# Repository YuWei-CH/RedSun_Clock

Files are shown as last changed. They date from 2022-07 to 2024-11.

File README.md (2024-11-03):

# RedSun_Clock
RedSun_Clock is a PCB-based clock that I designed and developed independently. The project was guided by Mr.Ethan and Mr.Matthew during the Google Hardware Product Sprint (HPS2022 Summer). 

This project consists of two main parts: Hardware and Software.

## Hardware
The hardware part includes the design of the circuit board and the bill of materials (BOM).
Essential components:
LED Matrix  
Micro-controller(atmega328)  
Quartz crystal unit  
Printed Circuit Board  

## Software
The software part is composed of code written in Arduino, which drives the operation of the hardware. And I use KiCAD for PCB design and verification.

## How to compile the code
You can use the Arduino compiler to compile this code.

## Picture
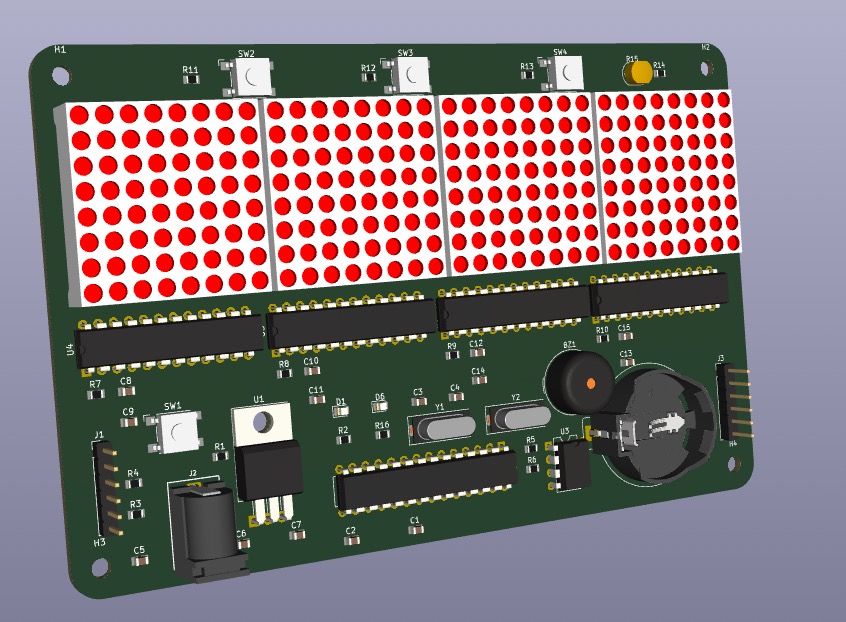
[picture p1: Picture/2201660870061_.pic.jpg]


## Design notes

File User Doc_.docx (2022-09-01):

User Doc

RedSun Clock is a smart clock based on ATmega328p. The RedSun Clock uses a beautiful dot matrix as the display module and makes it easy to read the time and information.

1. Design and architecture

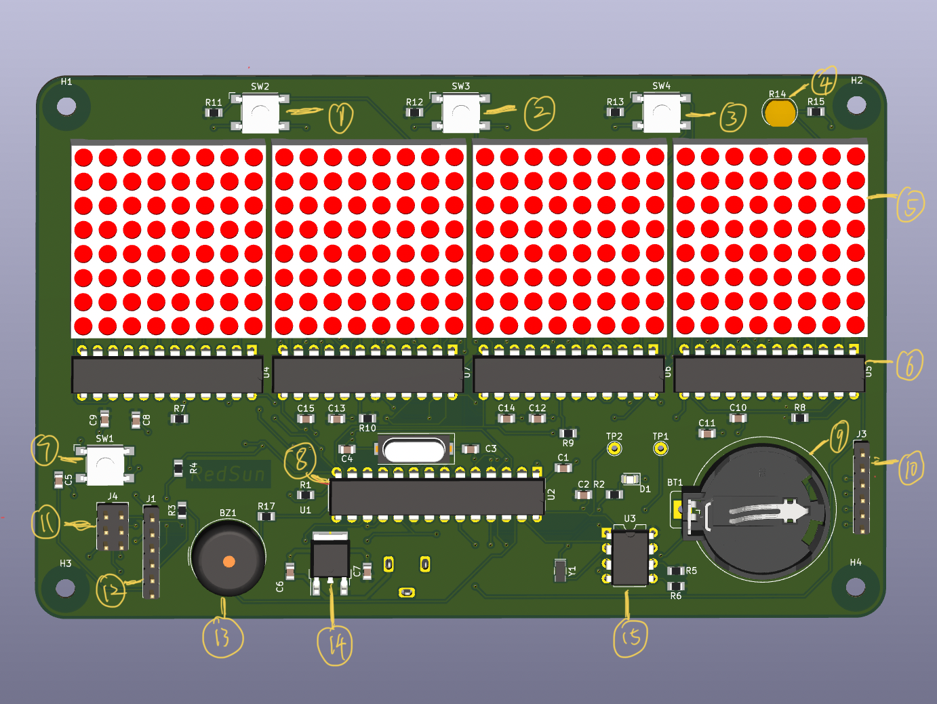
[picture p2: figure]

（Front 3D View of RedSum Clock）

- 1.Up/Daytime button
- 2.Down/ Datetime button
- 3.Sel/ Seconds button
- 4.Photoresistor
- 5. 8*8*4 dot matrix display
- 6. Max7219 chip(display processing chip)
- 7. Reset button
- 8. ATmega328P chip(micro controller)
- 9. Battery for RTC(real time clock)
- 10. Serial pins for joysticker
- 11. I/O pins
- 12. Serial pins
- 13. Alarm buzzer
- 14. Power management chip
- 15. DS1307 module (RTC)

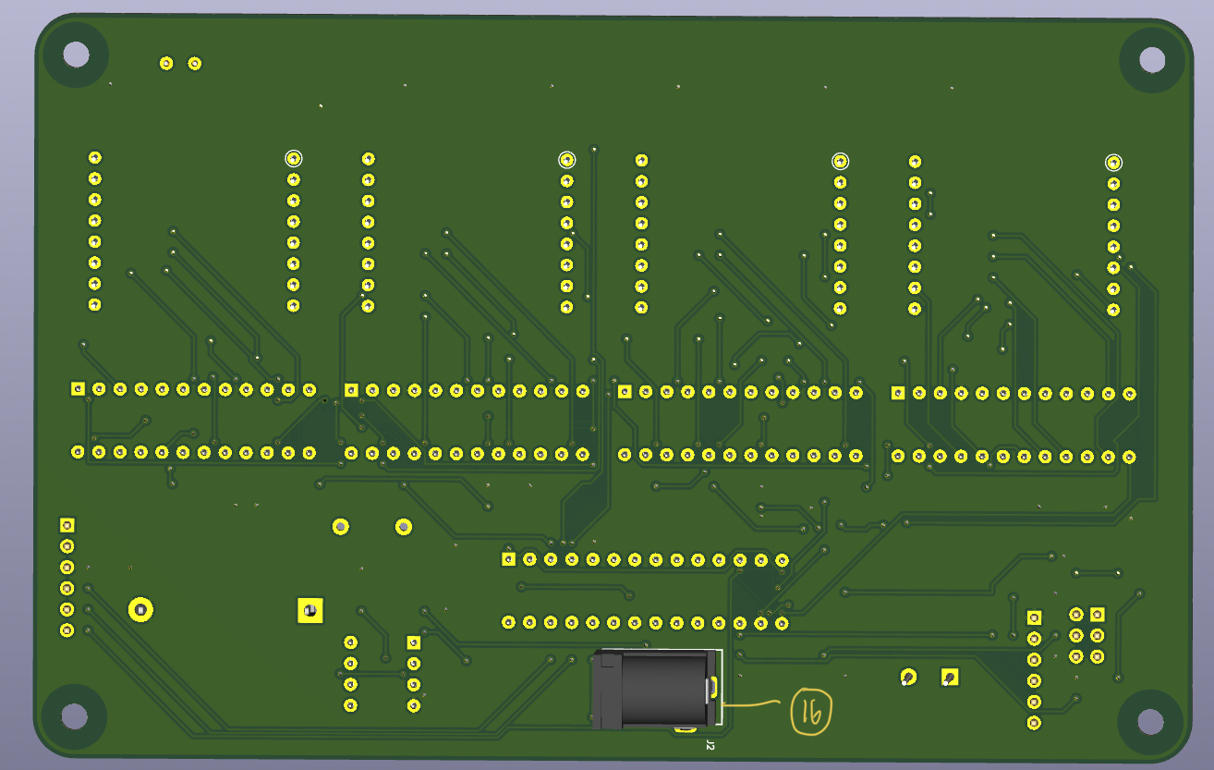
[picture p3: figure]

(Back 3D View of RedSum Clock)

- 16. Power supply
2. End-User Guide (Functions, charges, requirements)

Functions:

Time display function: When the RedSun Clock is powered on, the time will be automatically displayed on the display module. If you need to display Datetime, please press (2-button). If seconds need to be displayed, press (3-button).

Alarm Clock Function: The alarm clock function can be used when the RedSun Clock is powered on. To use the alarm function, press the Joysticker first, then the RedSun Clock will display "00:00" (if other content is displayed, please refer to the common question section). Once the screen correctly displays "00:00", the user can use the joysticker to set the time of the alarm. joysticker up increases the time and down decreases the time. To the left or to the right is to switch between hours and minutes. When the alarm is set, press the joysticker again and the alarm will be saved.

Charges：

A 9v battery can be used to provide power or a round interface charger with a power adaptor. Do not touch the circuit in the energized state to avoid electric shock or short circuit.

Requirements：

1. Please keep your RedSun Clock in a dry and ventilated environment. Please also avoid direct sunlight.

2. It is necessary to install a RedSun Clock into the plastic case.

3. If the RedSun Clock overheats, please disconnect the power promptly.

Please do not touch the circuit board with conductors or live objects.

3. Source code address and simple code address

Code resource: https://github.com/YuWei-CH/Yuwei_Clock/tree/main/Code/ClockCode

Test code link: https://github.com/YuWei-CH/Yuwei_Clock/tree/main/Code/Test

(If there is a functional problem on RedSun Clock, you can use the Test code to troubleshoot it.)

4. Test guide

If users have solid knowledge of EE and CS, they can use Test plan to self-test.

0. Visual Inspection:

1.Mechanical Damage

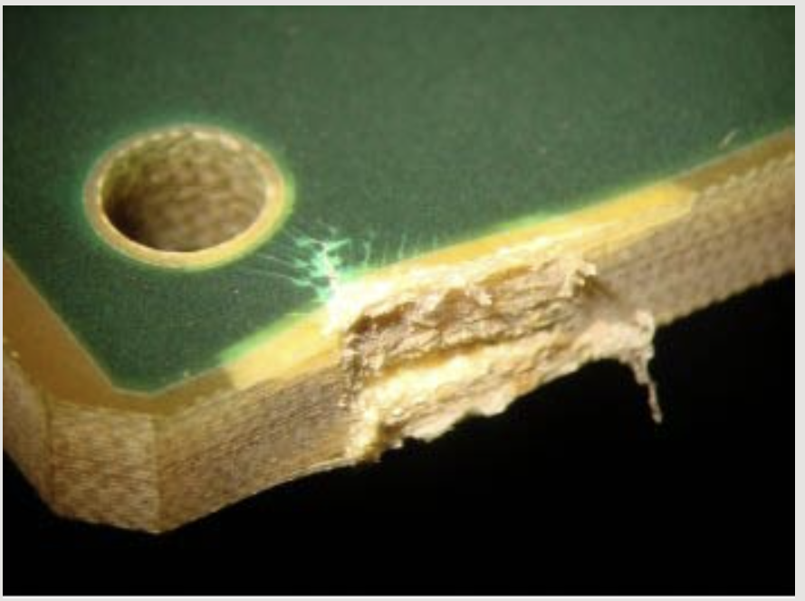
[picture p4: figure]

2.Copper Scratches

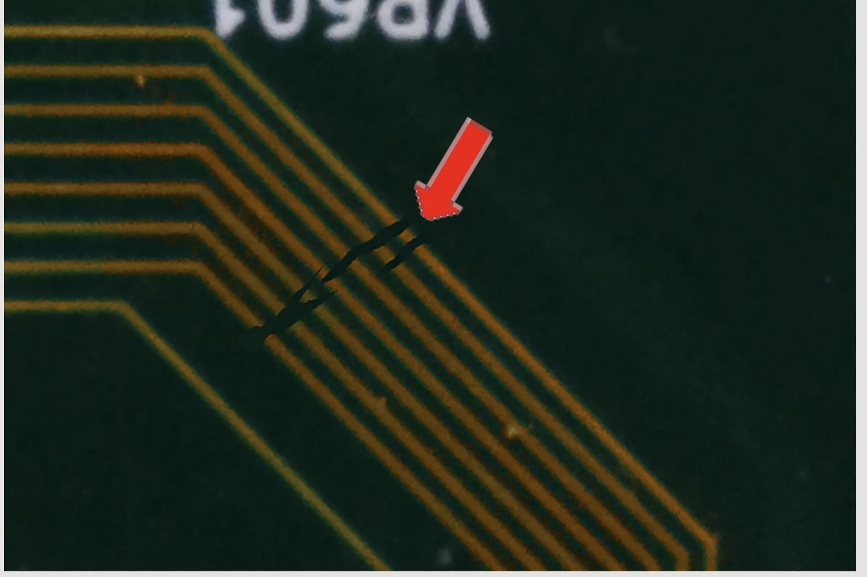
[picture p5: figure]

3.Solder Bridging

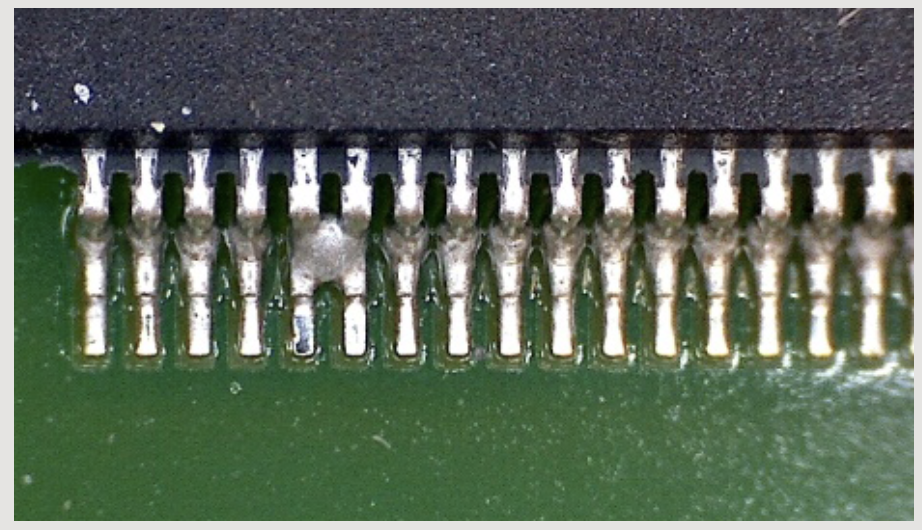
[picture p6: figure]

4.Cold Solder Joint

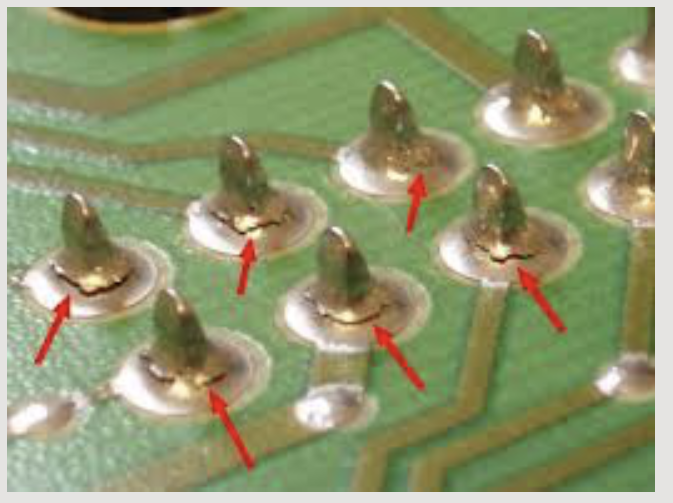
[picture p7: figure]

1. LED:

1.Test power and luminance of LED.

2.Run LED_blink code to test LED and Button

2. Button:

1.4 pins of the button are intact and working properly.

3. DS1307:

1.Can be powered by the breadboard

2.Battery works properly

3.You can use the 3 tests of Memory.ino

4.Capable of accurate time feedback (9600)

5. Touch the test pin with a voltmeter, the voltmeter should show the value

4.Dot matrix:

1. Test by “double for-loop print” which lights up each dot one by one, test whether each dot can be properly displayed.

2. Light up each row and test if there are any short circuits.

3. Call the display function to display the number.

4. Test the code in Dot_matrix_display

5. Buzzer:

1.Make sure it can sound through run code buzzer code

6. Joysticker:

1.Toggle the joysticker in all four directions and observe the values displayed by Serial.

2.Press the joysticker to make sure the value of SW in Serial has changed.

7. Power:

1.Use a voltmeter to connect the test pin next to the power supply, the voltmeter voltage reading should be 5v-9v

8. Basic Function:

Run the code in Yuwei_Clock/Code/Test one by one. Each component should have a corresponding reaction, for example, the LED will blink and Dot_matric will show the pattern.

9.Advance Function:

1. Does the Dot matrix display the correct time (hour:minute)?

2. Does the dot matrix display the date time (month/day/year) when the middle button is pressed?

3. Does the dot matrix show seconds after pressing the right button?

4. Does the dot matrix turn dark after covering the photoresistor with your hand?

5. Does the LED light up when the joysticker is pressed?

6. After pressing the joysticker, the system will enter the alarm setting mode. Is the dot matrix displayed correctly when moving the joysticker up and down and left and right?

7. After the alarm is set, does the buzzer go off at the alarm time and turn off within 4 seconds?

5. Help guide && Common questions and problems

What to do if the alarm clock does not display: First, please restart RedSun Clock to ensure that the power supply is working properly. If there is no response after reboot, please press 1-button. if you have completed the above operations, you can try upload test code to troubleshoot the problem.

The clock displays the wrong content: If the content displayed is digital you can update the program again to reset the RTC.

Inaccurate time: Please check if the RTC battery is properly powered. If the displayed number is three digits, please refer to question 2.

The button is not responding: Please restart RedSun Clock to reset the hardware system. If there is no response after reboot, please check if the pins of the button are broken and if there are scratches on the circuit board under the button. If the problem persists, it is a hardware issue.

Joysticker is not responding: Please check if the Pins are properly connected. secondly, you can check if there is a short circuit in the connection of joysticker.

The alarm clock is not responding: First, please try to reset the alarm clock. If it still does not respond you can follow the order of (buzzer, joysticker and RTC) to check if the hardware is intact. If the hardware is intact, please upload the test code about the alarm to troubleshoot the problem.

The alarm clock can not be turned off automatically: first of all, it is recommended to turn off the RedSun clock, and then you can check whether the buzzer is short-circuited. If there is no problem, please re-upload the program.

What to do if you get an error writing the program: Please update the environment of Arduino IDE. Go to Arduino and click update one by one in the managed libraries window. If you have any problems with the program, please leave a comment on Github.

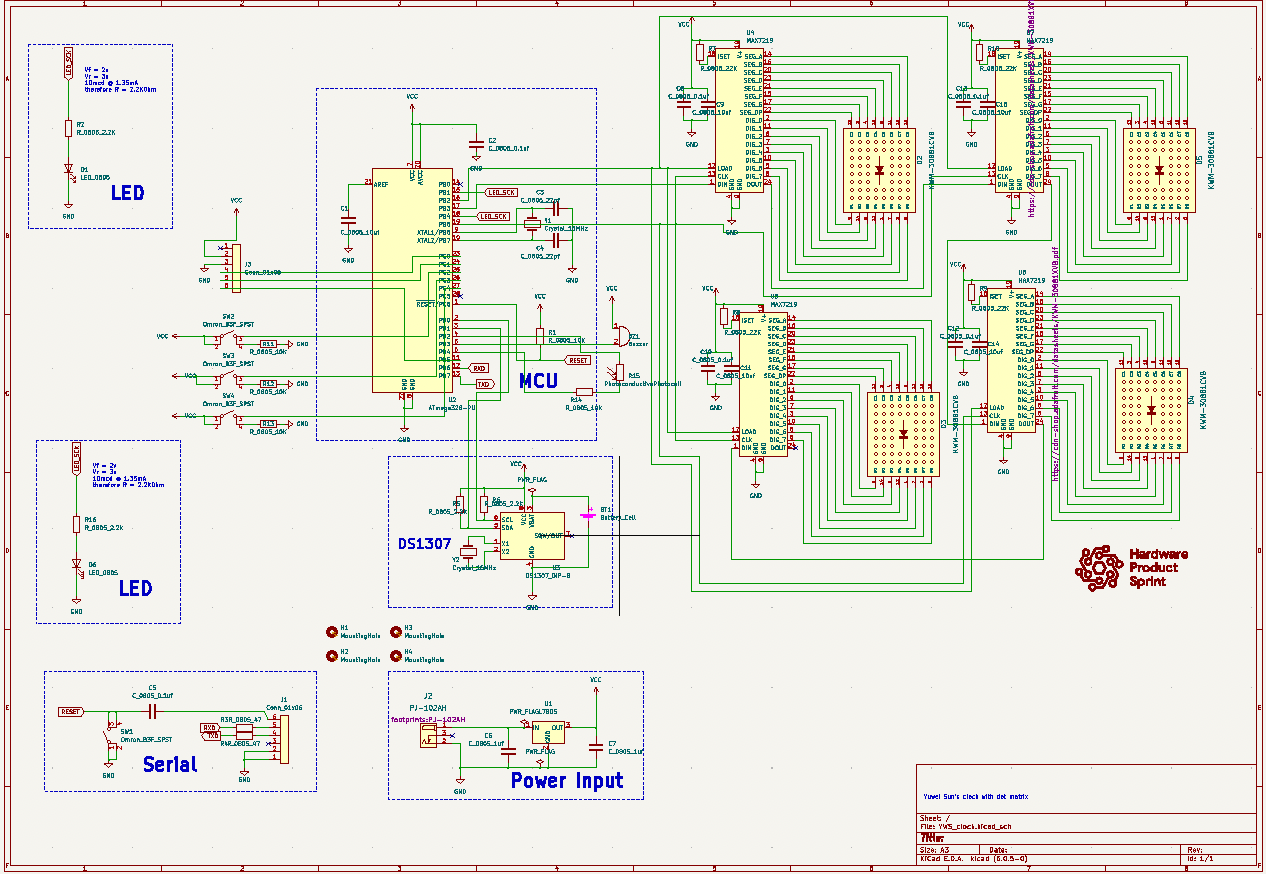
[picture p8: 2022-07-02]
Hardware/PCB design/image/schematic 1.0.png

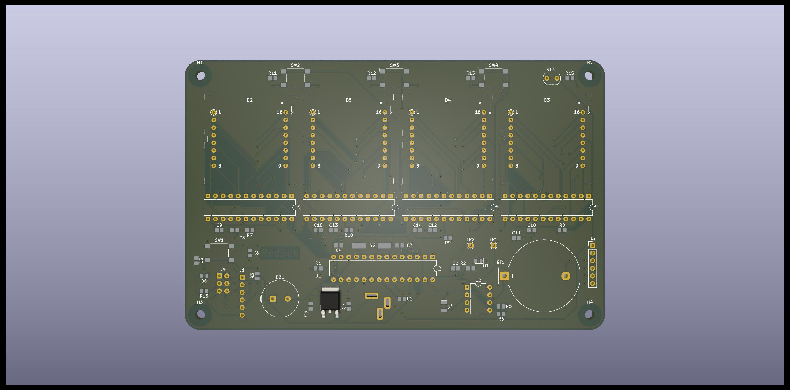
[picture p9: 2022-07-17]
Hardware/PCB design/image/YWS_clock.jpg

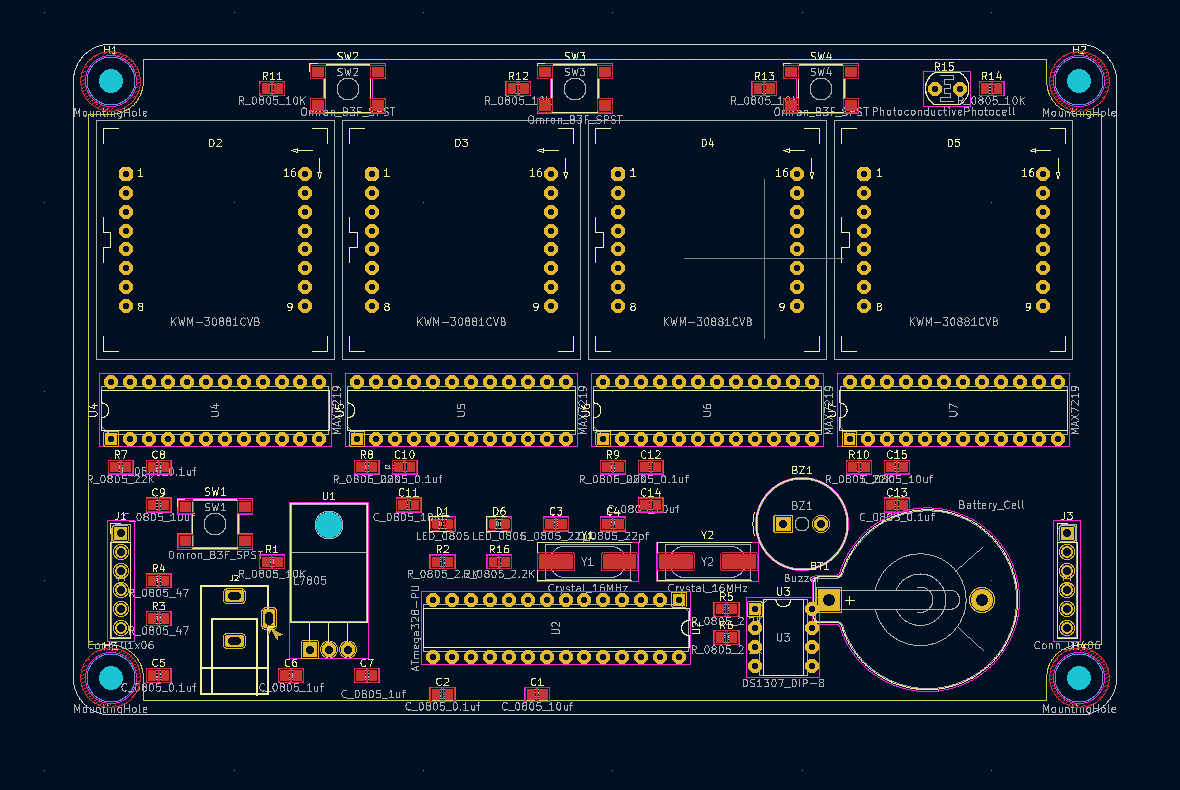
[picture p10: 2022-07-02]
Hardware/PCB design/image/PCB 1.0.png

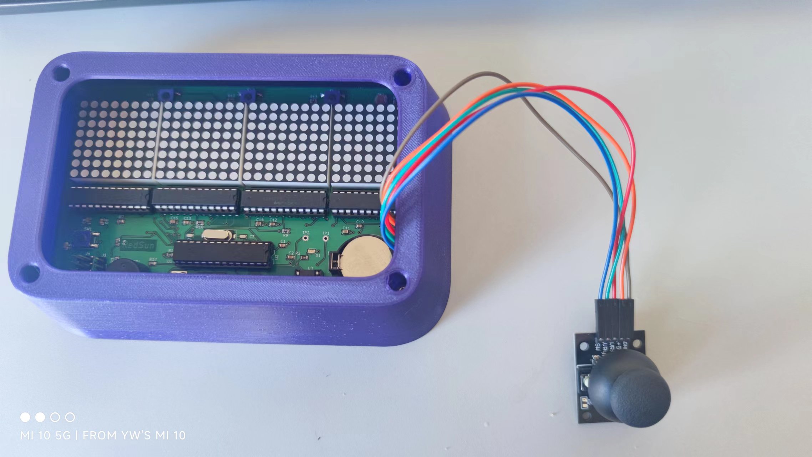
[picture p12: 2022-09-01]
Picture/2231661291328_.pic.jpg

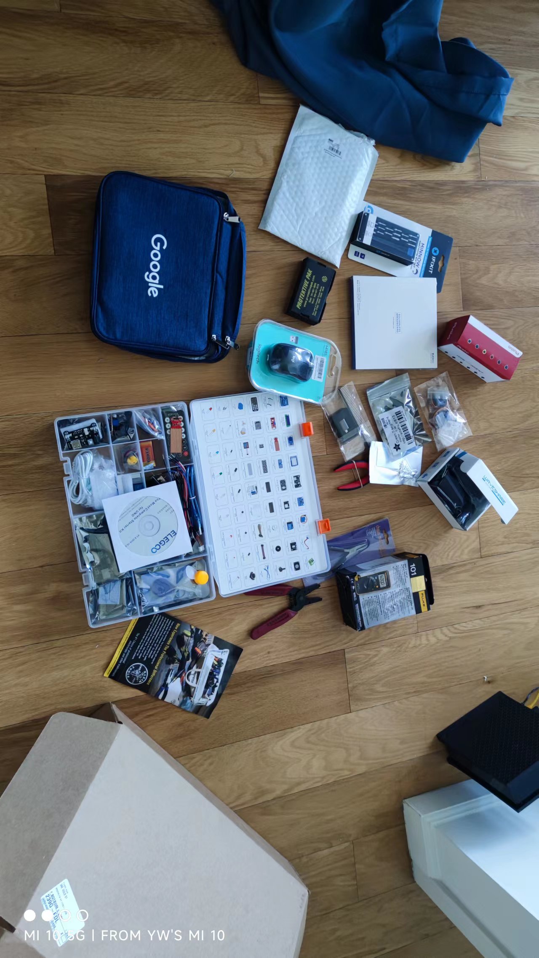
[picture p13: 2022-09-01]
Picture/2241662067455_.pic.jpg

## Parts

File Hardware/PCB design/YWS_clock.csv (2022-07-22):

Id | Designator | Package | Quantity | Designation | Supplier and ref
1 | U5,U4,U6,U7 | DIP-24_W7.62mm | 4 | MAX7219
2 | TP1,TP2 | TestPoint_THTPad_D2.0mm_Drill1.0mm | 2 | TestPoint
3 | BZ1 | Buzzer_TDK_PS1240P02BT_D12.2mm_H6.5mm | 1 | Buzzer
4 | H4,H2,H3,H1 | MountingHole_3.2mm_M3 | 4 | MountingHole
5 | C9,C14,C1,C11,C15 | C_0805_2012Metric | 5 | C_0805_10uf
6 | C6 | C_0805_2012Metric | 1 | C_0805_1uf
7 | Y1 | Crystal_SMD_2Pin_3.2x1.5mm | 1 | Crystal_32768Hz
8 | U3 | DIP-8_W7.62mm | 1 | DS1307_DIP-8
9 | R16,R2 | R_0805_2012Metric | 2 | R_0805_2.2K
10 | D4,D2,D5,D3 | KWM-30881CVB | 4 | KWM-30881CVB
11 | R5,R6 | R_0805_2012Metric | 2 | R_0805_4.7K
12 | R17,R4,R3 | R_0805_2012Metric | 3 | R_0805_47
13 | J3,J1 | PinHeader_1x06_P2.54mm_Vertical | 2 | Conn_01x06
14 | SW3,SW2,SW4,SW1 | SW_SPST_Omron_B3FS-100xP | 4 | Omron_B3F_SPST
15 | R13,R1,R11,R12 | R_0805_2012Metric | 4 | R_0805_10K
16 | C3,C4 | C_0805_2012Metric | 2 | C_0805_22pf
17 | C12,C8,C13,C2,C7,C5,C10 | C_0805_2012Metric | 7 | C_0805_0.1uf
18 | R15 | R_0805_2012Metric | 1 | R_0805_100K
19 | R14 | R_LDR_4.9x4.2mm_P2.54mm_Vertical | 1 | PhotoconductivePhotocell
20 | U2 | DIP-28_W7.62mm | 1 | ATmega328-PU
21 | Y2 | Crystal_SMD_HC49-SD | 1 | Crystal_16MHz
22 | R10,R7,R9,R8 | R_0805_2012Metric | 4 | R_0805_22K
23 | U1 | TO-252-2 | 1 | L7805
24 | BT1 | BatteryHolder_Keystone_106_1x20mm | 1 | Battery_Cell
25 | D6,D1 | LED_0805_2012Metric | 2 | LED_0805
26 | J4 | PinHeader_2x03_P2.54mm_Vertical | 1 | Conn_02x03_Odd_Even
27 | J2 | Wurth-694106402002 | 1 | Power_inlet_vertical

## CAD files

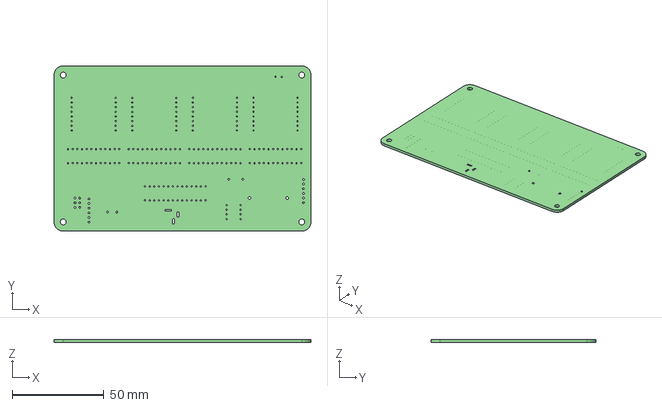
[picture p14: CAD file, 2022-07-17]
Hardware/PCB design/YWS_clock.step
140.0 x 90.0 x 1.60 mm

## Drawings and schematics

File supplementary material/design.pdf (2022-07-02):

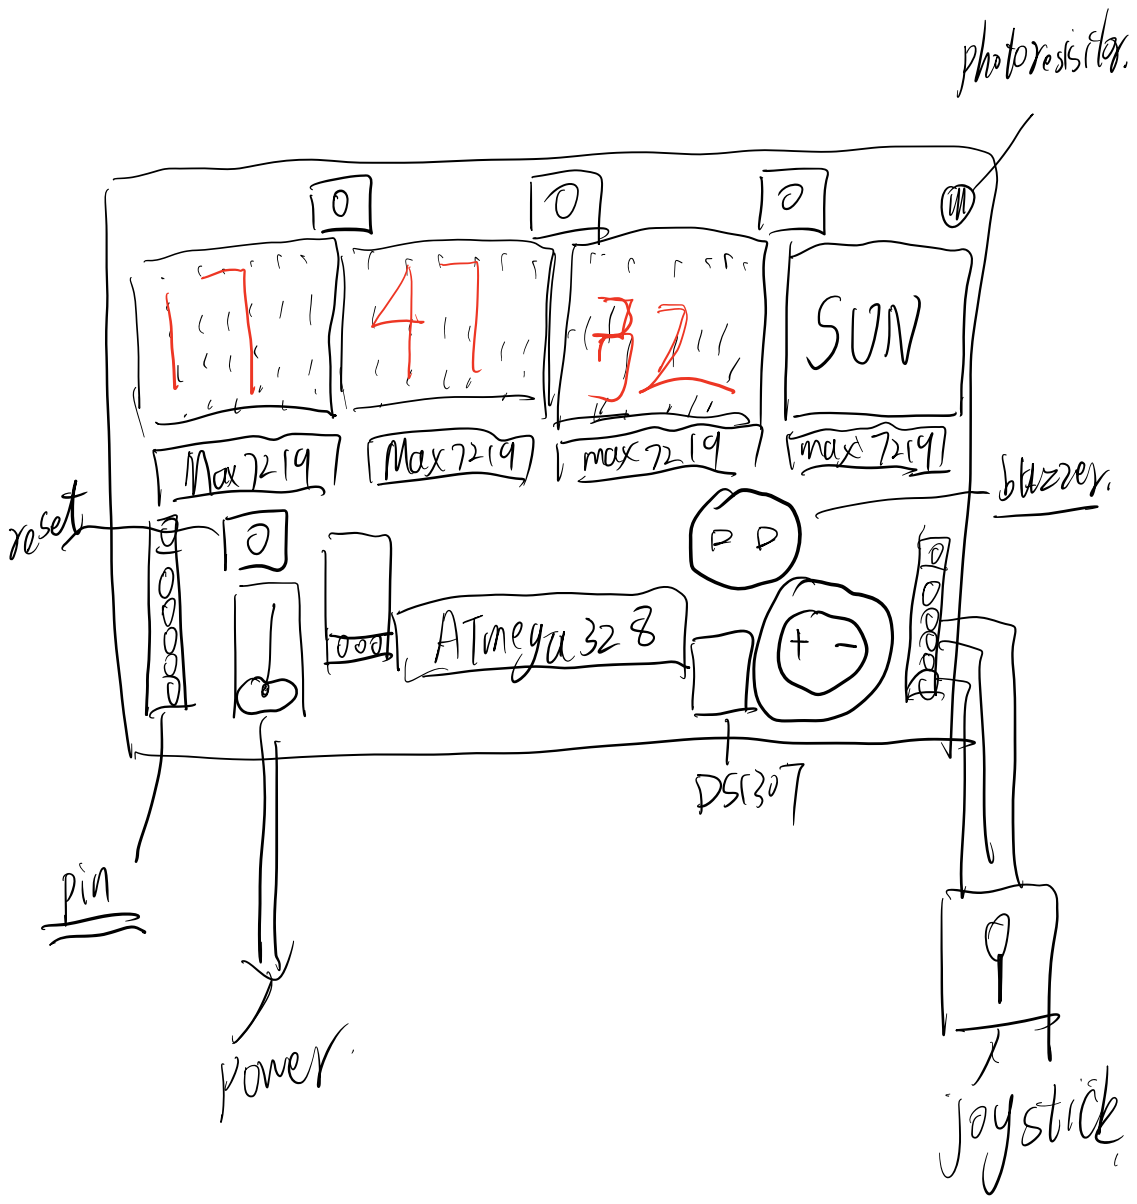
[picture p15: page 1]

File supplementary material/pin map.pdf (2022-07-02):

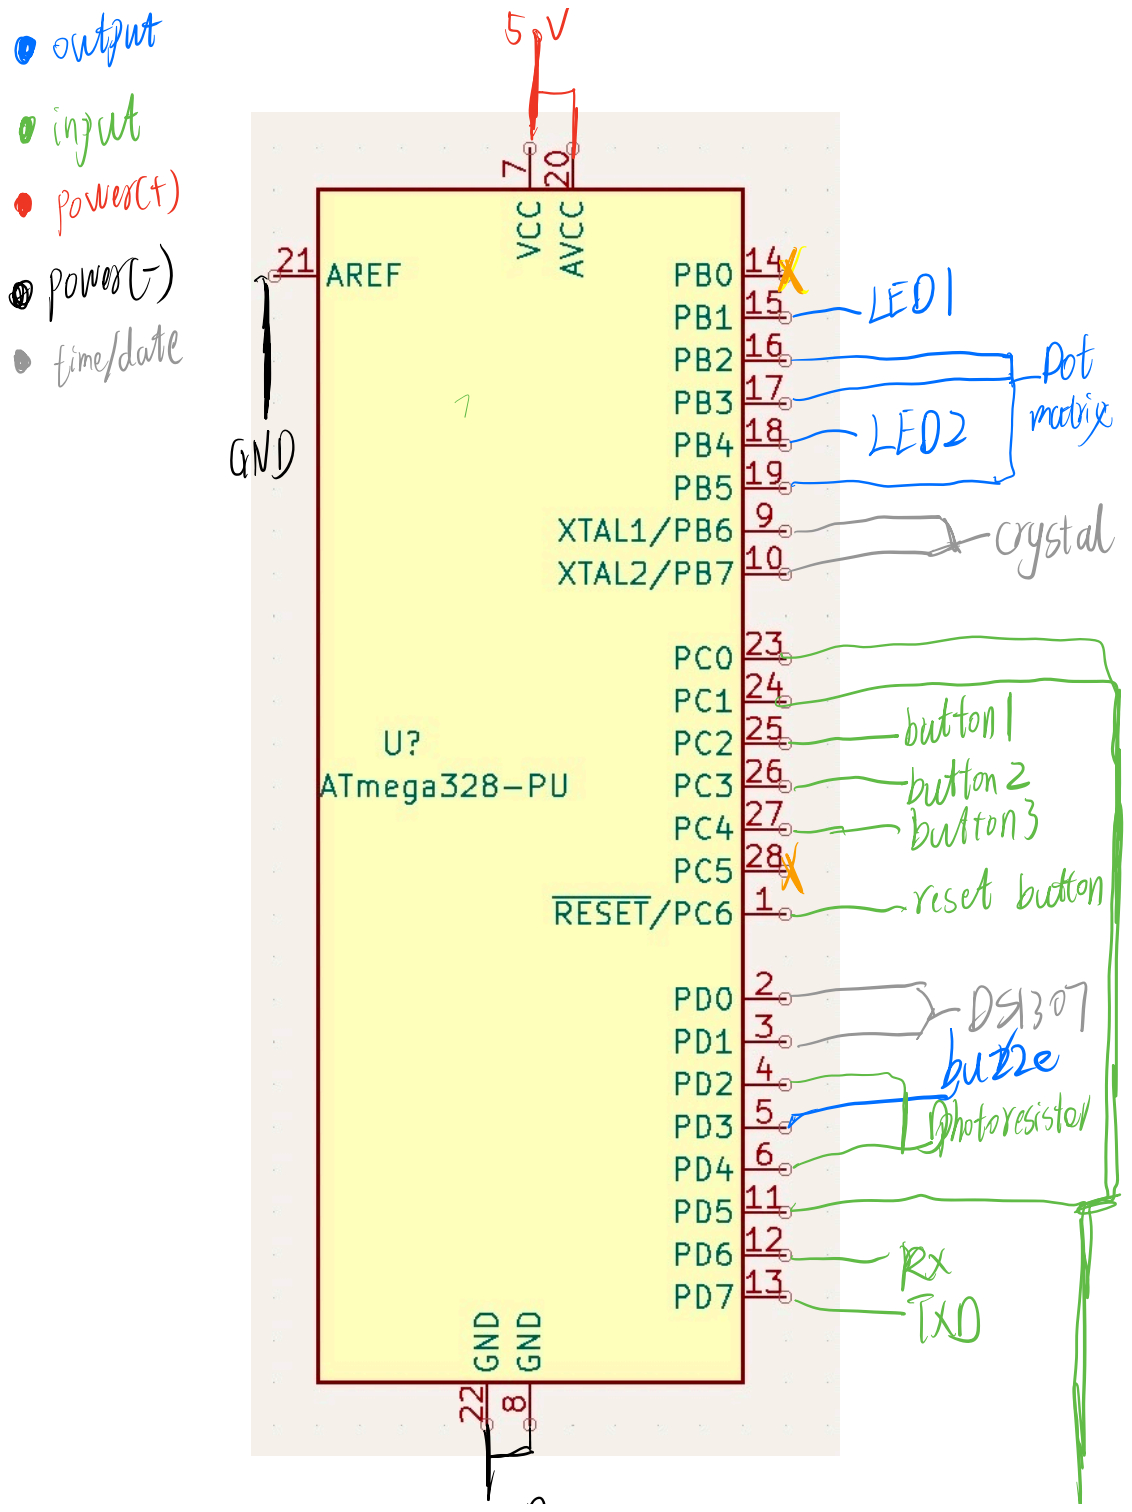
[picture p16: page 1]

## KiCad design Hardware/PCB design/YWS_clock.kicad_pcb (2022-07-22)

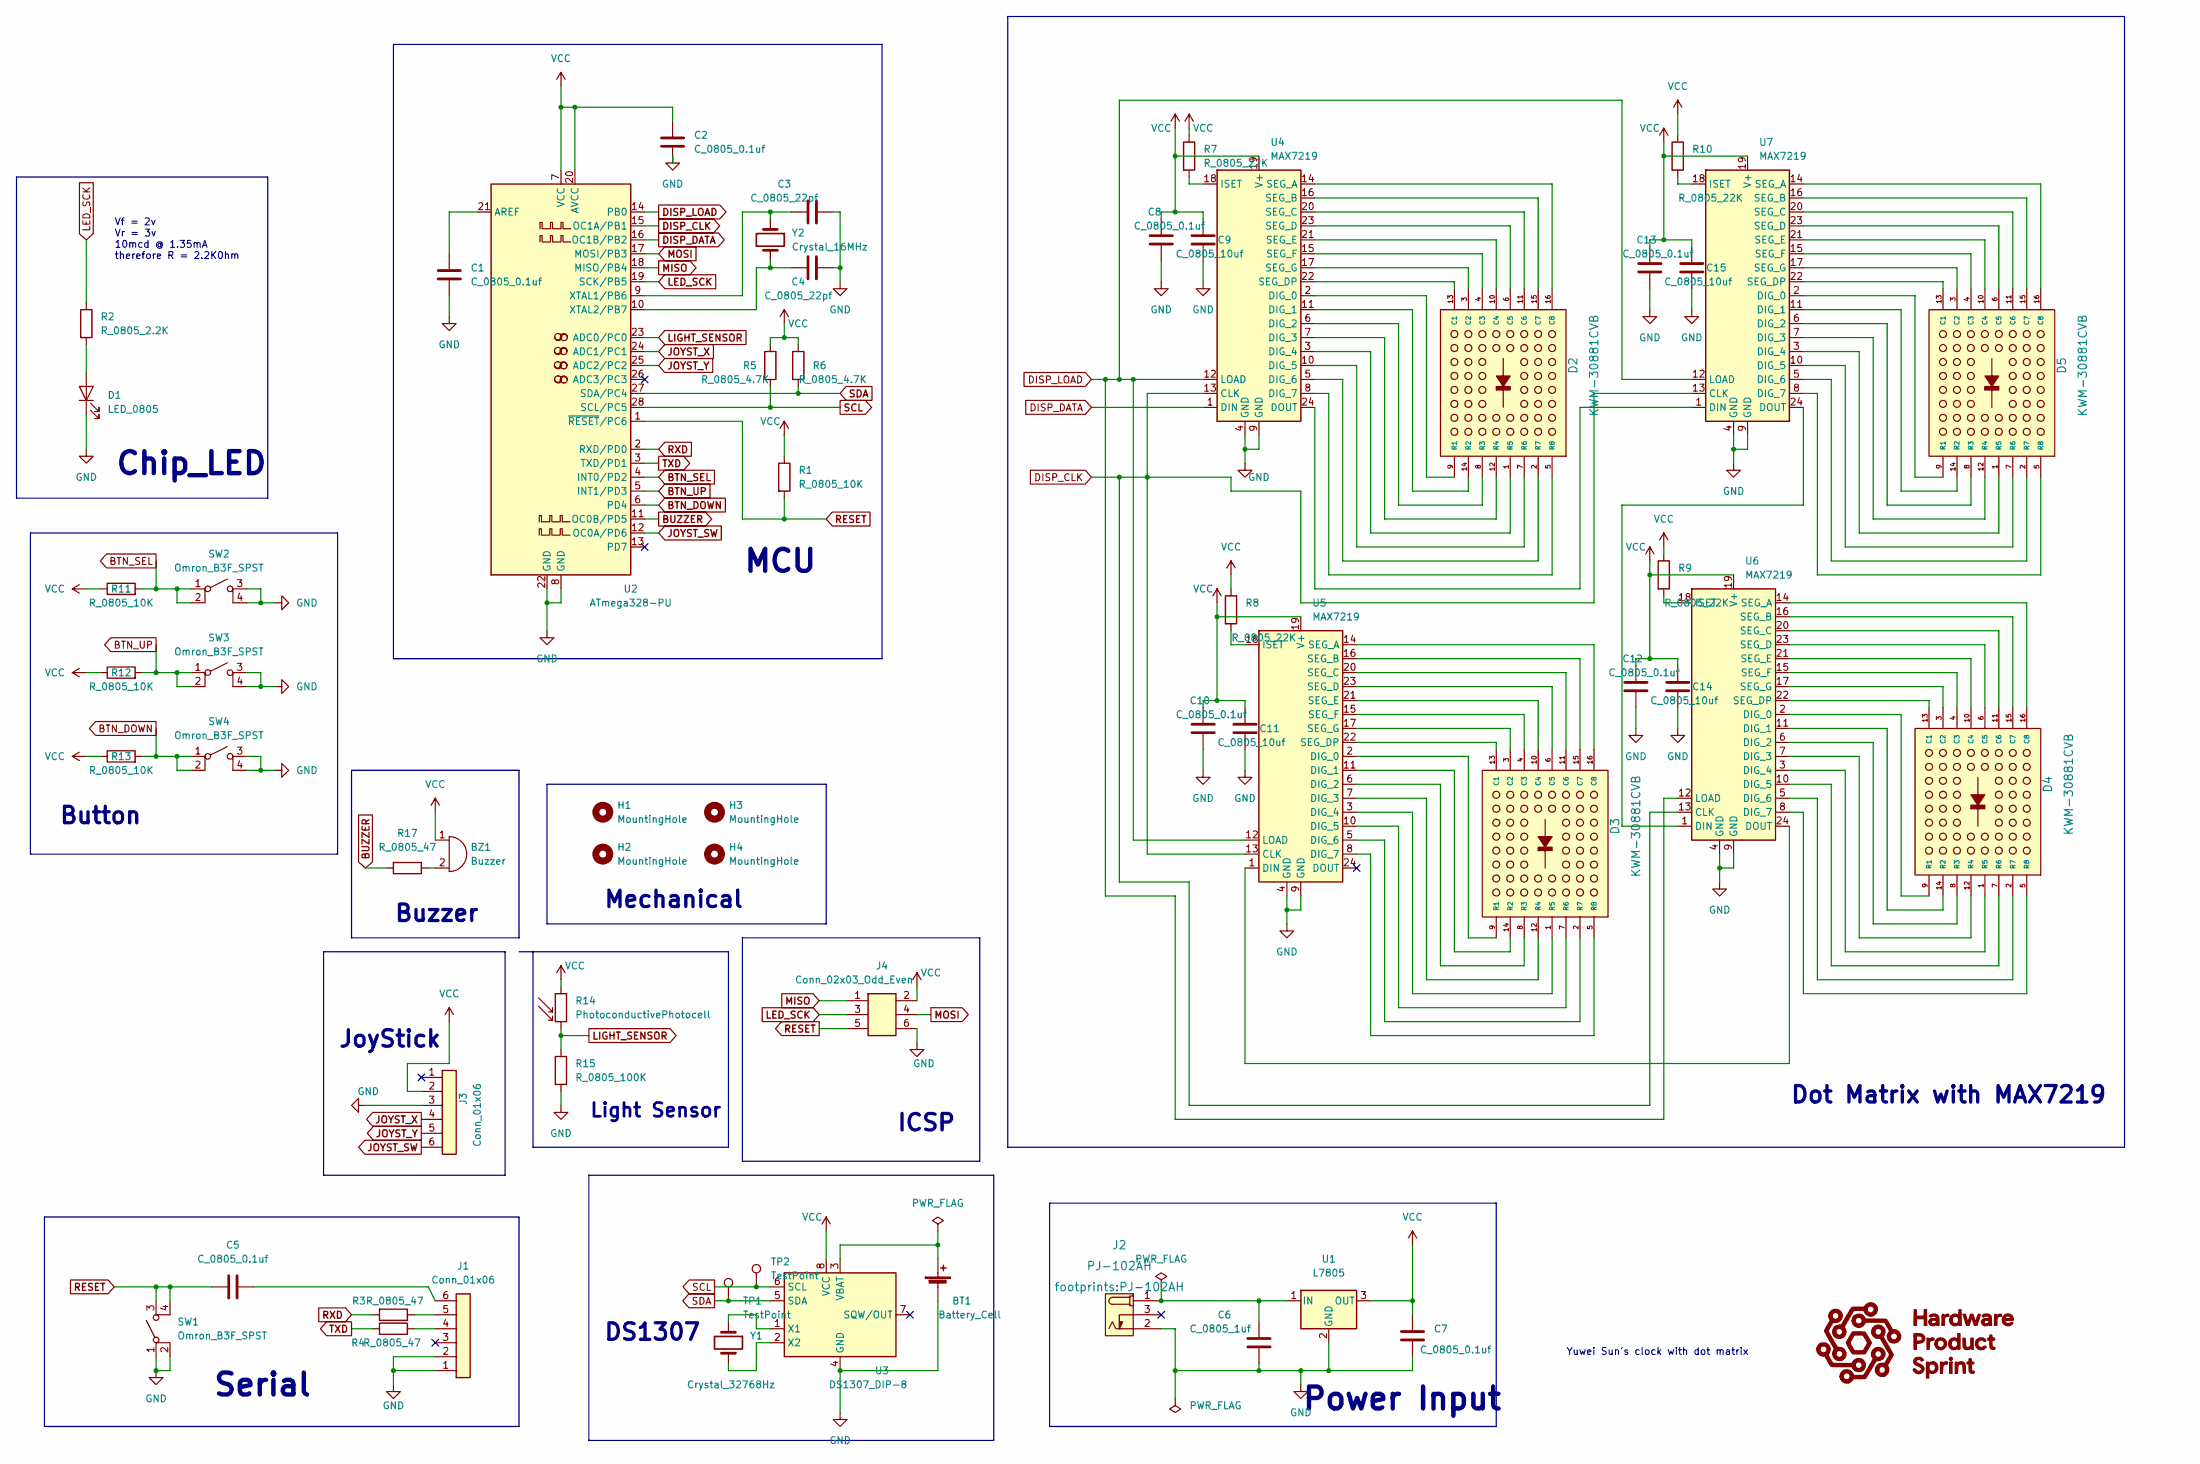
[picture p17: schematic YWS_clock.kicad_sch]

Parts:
BT1: Battery_Cell; BatteryHolder_Keystone_106_1x20mm; MPN BS-7; Digikey PN BS-7-ND
BZ1: Buzzer; Buzzer_TDK_PS1240P02BT_D12.2mm_H6.5mm; MPN PS1420P02CT; Digikey PN 445-2526-1-ND
C1, C2, C5, C7, C8, C10, C12, C13: C_0805_0.1uf; C_0805_2012Metric; Voltage N/A; Tolerance N/A; MPN 08055C104KAT2A; Digikey PN 478-1395-1-ND
C3, C4: C_0805_22pf; C_0805_2012Metric; Voltage N/A; Tolerance N/A; MPN CC0805JRNPO9BN220; Digikey PN 311-1103-1-ND
C6: C_0805_1uf; C_0805_2012Metric; Voltage N/A; Tolerance N/A; MPN CC0805KKX7R8BB105; Digikey PN 311-1456-1-ND
C9, C11, C14, C15: C_0805_10uf; C_0805_2012Metric; Voltage N/A; Tolerance N/A; MPN GRM21BR61E106KA73L; Digikey PN 490-5523-1-ND
D1: LED_0805; LED_0805_2012Metric; MPN 150080RS75000; Digikey PN 732-4984-1-ND
D2, D3, D4, D5: KWM-30881CVB; MPN KWM-30881CVB; Digikey PN N/A
H1, H2, H3, H4: MountingHole; MountingHole_3.2mm_M3
J1, J3: Conn_01x06; PinHeader_1x06_P2.54mm_Vertical; MPN 61300611121; Digikey PN 732-5319-ND
J2: PJ-102AH; MPN PJ-102AH; Digikey PN CP-102AH-ND
J4: Conn_02x03_Odd_Even; PinHeader_2x03_P2.54mm_Vertical; MPN PRPC003DAAN-RC; Digikey PN S2011EC-03-ND
R1, R11, R12, R13: R_0805_10K; R_0805_2012Metric; Tolerance N/A; MPN RC0805FR-0710KL; Digikey PN 311-10.0KCRCT-ND
R2: R_0805_2.2K; R_0805_2012Metric; Tolerance N/A; MPN N/A; Digikey PN 311-2.20KCRCT-ND
R3, R4, R17: R_0805_47; R_0805_2012Metric; Tolerance N/A; Mouser PN N/A; Digikey PN RC0805FR-0747RL
R5, R6: R_0805_4.7K; R_0805_2012Metric; Tolerance N/A; MPN RC0805FR-074K7L; Digikey PN 311-4.70KCRCT-ND
R7, R8, R9, R10: R_0805_22K; R_0805_2012Metric; Tolerance N/A; MPN RC0805FR-0722KL; Digikey PN 311-22.0KCRCT-ND
R14: PhotoconductivePhotocell; R_LDR_4.9x4.2mm_P2.54mm_Vertical; Voltage N/A; Tolerance N/A; MPN PDV-P8103; Digikey PN PDV-P8103-ND
R15: R_0805_100K; R_0805_2012Metric; Tolerance N/A; MPN RC0805FR-07100KL; Digikey PN 311-100KCRCT-ND
SW1, SW2, SW3, SW4: Omron_B3F_SPST; SW_SPST_Omron_B3FS-100xP; MPN B3FS-1000P; Digikey PN SW423CT-ND
TP1, TP2: TestPoint; TestPoint_THTPad_D2.0mm_Drill1.0mm
U1: L7805; TO-252-2; MPN L7805CDT-TR; Digikey PN 497-7255-1-ND
U2: ATmega328-PU; DIP-28_W7.62mm; MPN ED281DT; Digikey PN ED3050-5-ND
U3: DS1307_DIP-8; DIP-8_W7.62mm; MPN A 08-LC-TT; Digikey PN AE9986-ND
U4, U5, U6, U7: MAX7219; DIP-24_W7.62mm; MPN ED241DT; Digikey PN ED3049-5-ND
Y1: Crystal_32768Hz; Crystal_SMD_2Pin_3.2x1.5mm; MPN Q 0,032768-JTX310-12,5-20-T1-HMR-50K-LF; Digikey PN 1908-1314-1-ND
Y2: Crystal_16MHz; Crystal_SMD_HC49-SD; MPN ECS-160-20-5PXDN-TR; Digikey PN XC1299CT-ND

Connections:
BTN_DOWN: R13.2, SW4.1 (A), SW4.2 (A), U2.6 (PD4)
BTN_SEL: R11.2, SW2.1 (A), SW2.2 (A), U2.4 (INT0/PD2)
BTN_UP: R12.2, SW3.1 (A), SW3.2 (A), U2.5 (INT1/PD3)
BUZZER: R17.2, U2.11 (OC0B/PD5)
DISP_CLK: U2.15 (OC1A/PB1), U4.13 (CLK), U5.13 (CLK), U6.13 (CLK), U7.13 (CLK)
DISP_DATA: U2.16 (OC1B/PB2), U4.1 (DIN)
DISP_LOAD: U2.14 (PB0), U4.12 (LOAD), U5.12 (LOAD), U6.12 (LOAD), U7.12 (LOAD)
GND: BT1.2 (-), C1.2, C2.2, C3.2, C4.2, C6.2, C7.2, C8.2, C9.2, C10.2, C11.2, C12.2, C13.2, C14.2, C15.2, D1.1 (K), J1.1, J1.2, J2.2 (OUT), J3.3, J4.6, R15.2, SW1.1 (A), SW1.2 (A), SW2.3 (B), SW2.4 (B), SW3.3 (B), SW3.4 (B), SW4.3 (B), SW4.4 (B), U1.2 (GND), U2.8 (GND), U2.22 (GND), U3.4 (GND), U4.4 (GND), U4.9 (GND), U5.4 (GND), U5.9 (GND), U6.4 (GND), U6.9 (GND), U7.4 (GND), U7.9 (GND)
JOYST_SW: J3.6, U2.12 (OC0A/PD6)
JOYST_X: J3.4, U2.24 (ADC1/PC1)
JOYST_Y: J3.5, U2.25 (ADC2/PC2)
LED_SCK: J4.3, R2.1, U2.19 (SCK/PB5)
LIGHT_SENSOR: R14.2, R15.1, U2.23 (ADC0/PC0)
MISO: J4.1, U2.18 (MISO/PB4)
MOSI: J4.4, U2.17 (MOSI/PB3)
unnamed: BT1.1 (+), U3.3 (VBAT)
unnamed: BZ1.2 (+), R17.1
unnamed: C1.1, U2.21 (AREF)
unnamed: C3.1, U2.9 (XTAL1/PB6), Y2.1
unnamed: C4.1, U2.10 (XTAL2/PB7), Y2.2
unnamed: C5.2, J1.6
unnamed: C6.1, J2.1 (POLE), U1.1 (IN)
unnamed: D1.2 (A), R2.2
unnamed: D2.1 (R5), U4.3 (DIG_4)
unnamed: D2.2 (R7), U4.5 (DIG_6)
unnamed: D2.3 (C2), U4.17 (SEG_G)
unnamed: D2.4 (C3), U4.15 (SEG_F)
unnamed: D2.5 (R8), U4.8 (DIG_7)
unnamed: D2.6 (C5), U4.23 (SEG_D)
unnamed: D2.7 (R6), U4.10 (DIG_5)
unnamed: D2.8 (R3), U4.6 (DIG_2)
unnamed: D2.9 (R1), U4.2 (DIG_0)
unnamed: D2.10 (C4), U4.21 (SEG_E)
unnamed: D2.11 (C6), U4.20 (SEG_C)
unnamed: D2.12 (R4), U4.7 (DIG_3)
unnamed: D2.13 (C1), U4.22 (SEG_DP)
unnamed: D2.14 (R2), U4.11 (DIG_1)
unnamed: D2.15 (C7), U4.16 (SEG_B)
unnamed: D2.16 (C8), U4.14 (SEG_A)
unnamed: D3.1 (R5), U5.3 (DIG_4)
unnamed: D3.2 (R7), U5.5 (DIG_6)
unnamed: D3.3 (C2), U5.17 (SEG_G)
unnamed: D3.4 (C3), U5.15 (SEG_F)
unnamed: D3.5 (R8), U5.8 (DIG_7)
unnamed: D3.6 (C5), U5.23 (SEG_D)
unnamed: D3.7 (R6), U5.10 (DIG_5)
unnamed: D3.8 (R3), U5.6 (DIG_2)
unnamed: D3.9 (R1), U5.2 (DIG_0)
unnamed: D3.10 (C4), U5.21 (SEG_E)
unnamed: D3.11 (C6), U5.20 (SEG_C)
unnamed: D3.12 (R4), U5.7 (DIG_3)
unnamed: D3.13 (C1), U5.22 (SEG_DP)
unnamed: D3.14 (R2), U5.11 (DIG_1)
unnamed: D3.15 (C7), U5.16 (SEG_B)
unnamed: D3.16 (C8), U5.14 (SEG_A)
unnamed: D4.1 (R5), U6.3 (DIG_4)
unnamed: D4.2 (R7), U6.5 (DIG_6)
unnamed: D4.3 (C2), U6.17 (SEG_G)
unnamed: D4.4 (C3), U6.15 (SEG_F)
unnamed: D4.5 (R8), U6.8 (DIG_7)
unnamed: D4.6 (C5), U6.23 (SEG_D)
unnamed: D4.7 (R6), U6.10 (DIG_5)
unnamed: D4.8 (R3), U6.6 (DIG_2)
unnamed: D4.9 (R1), U6.2 (DIG_0)
unnamed: D4.10 (C4), U6.21 (SEG_E)
unnamed: D4.11 (C6), U6.20 (SEG_C)
unnamed: D4.12 (R4), U6.7 (DIG_3)
unnamed: D4.13 (C1), U6.22 (SEG_DP)
unnamed: D4.14 (R2), U6.11 (DIG_1)
unnamed: D4.15 (C7), U6.16 (SEG_B)
unnamed: D4.16 (C8), U6.14 (SEG_A)
unnamed: D5.1 (R5), U7.3 (DIG_4)
unnamed: D5.2 (R7), U7.5 (DIG_6)
unnamed: D5.3 (C2), U7.17 (SEG_G)
unnamed: D5.4 (C3), U7.15 (SEG_F)
unnamed: D5.5 (R8), U7.8 (DIG_7)
unnamed: D5.6 (C5), U7.23 (SEG_D)
unnamed: D5.7 (R6), U7.10 (DIG_5)
unnamed: D5.8 (R3), U7.6 (DIG_2)
unnamed: D5.9 (R1), U7.2 (DIG_0)
unnamed: D5.10 (C4), U7.21 (SEG_E)
unnamed: D5.11 (C6), U7.20 (SEG_C)
unnamed: D5.12 (R4), U7.7 (DIG_3)
unnamed: D5.13 (C1), U7.22 (SEG_DP)
unnamed: D5.14 (R2), U7.11 (DIG_1)
unnamed: D5.15 (C7), U7.16 (SEG_B)
unnamed: D5.16 (C8), U7.14 (SEG_A)
unnamed: J1.4, R4.2
unnamed: J1.5, R3.1
unnamed: R7.2, U4.18 (ISET)
unnamed: R8.2, U5.18 (ISET)
unnamed: R9.2, U6.18 (ISET)
unnamed: R10.2, U7.18 (ISET)
unnamed: U3.1 (X1), Y1.1
unnamed: U3.2 (X2), Y1.2
unnamed: U4.24 (DOUT), U7.1 (DIN)
unnamed: U5.1 (DIN), U6.24 (DOUT)
unnamed: U6.1 (DIN), U7.24 (DOUT)
RESET: C5.1, J4.5, R1.2, SW1.3 (B), SW1.4 (B), U2.1 (~RESET/PC6)
RXD: R3.2, U2.2 (RXD/PD0)
SCL: R5.2, TP2.1, U2.28 (SCL/PC5), U3.6 (SCL)
SDA: R6.2, TP1.1, U2.27 (SDA/PC4), U3.5 (SDA)
TXD: R4.1, U2.3 (TXD/PD1)
VCC: BZ1.1 (-), C2.1, C7.1, C8.1, C9.1, C10.1, C11.1, C12.1, C13.1, C14.1, C15.1, J3.2, J4.2, R1.1, R5.1, R6.1, R7.1, R8.1, R9.1, R10.1, R11.1, R12.1, R13.1, R14.1, U1.3 (OUT), U2.7 (VCC), U2.20 (AVCC), U3.8 (VCC), U4.19 (V+), U5.19 (V+), U6.19 (V+), U7.19 (V+)

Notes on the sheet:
MCU
JoyStick
ICSP
Serial
Power Input
Chip_LED
Buzzer
Yuwei Sun's clock with dot matrix
Vf = 2v Vr = 3v 10mcd @ 1.35mA therefore R = 2.2K0hm
Light Sensor
Dot Matrix with MAX7219
DS1307
Button
Mechanical

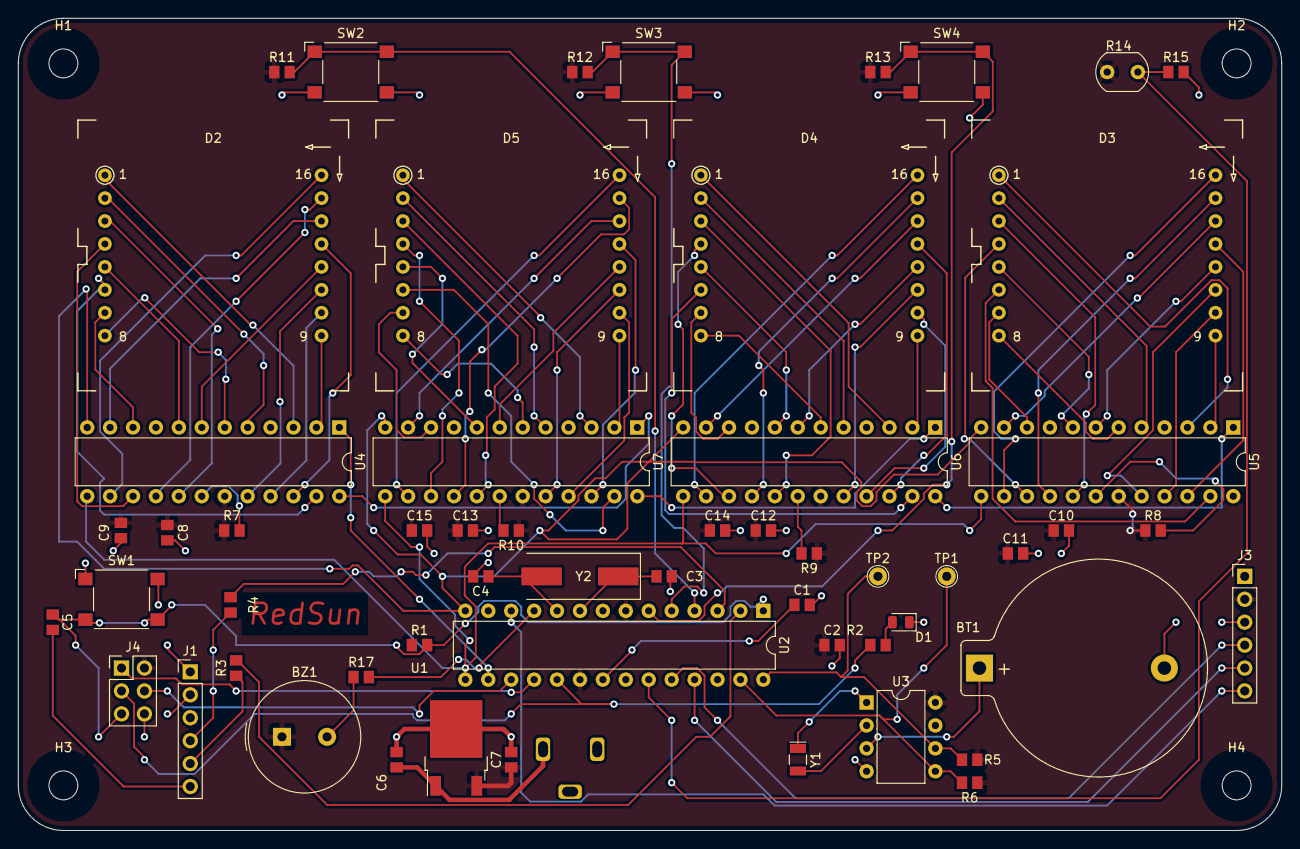
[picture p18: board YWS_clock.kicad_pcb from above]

Board: 2 copper layers, 140.0 x 90.0 mm, 61 parts (1 on the bottom side), 104 nets.

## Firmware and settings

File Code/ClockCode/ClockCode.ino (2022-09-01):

// Including the required Arduino dot matrix libraries
#include <MD_Parola.h>
#include <MD_MAX72xx.h>
#include <SPI.h>


// Including the required DS1307 libraries
#include <Wire.h> // must be included here so that Arduino library object file references work
#include <RtcDS1307.h>
RtcDS1307<TwoWire> Rtc(Wire); // include SOA and SCL


// Define for hardware type
#define HARDWARE_TYPE MD_MAX72XX::FC16_HW


// Define size, and output pins for RTC
#define MAX_DEVICES 4
#define CS_PIN 8
#define DATA_PIN 10
#define CLK_PIN 9


// Define for global variable
#define countof(a) (sizeof(a) / sizeof(a[0])) // method of count time
const char data[] = "Time is"; // Time display area(on serial)


// Create a new instance of the MD_Parola class with hardware SPI connection
MD_Parola myDisplay = MD_Parola(HARDWARE_TYPE, DATA_PIN, CLK_PIN, CS_PIN, MAX_DEVICES);

// Define Button var
int Sel = 2;
int Up = 3;
int Down = 4;
int dateButtonState = 0;
int secondButtonState = 0;

// Define LED var
int LED = 13;

// Define joystick var
int xPosition = 0;
int yPosition = 0;
int SW_state = 0;
int mapX = 0;
int mapY = 0;
int VRx = A1;
int VRy = A2;
int SW = 6;

// define buzzer
int buzzer = 5;

void setup() {

  // initialize digital pin LED as an output.
  pinMode(LED, OUTPUT);

  // initialize the pushbutton pin as an input:
  pinMode(Sel, INPUT); // Sel & DateTime (M/Y/D)
  pinMode(Up, INPUT); // UP & DayTime (H/M)
  pinMode(Down, INPUT); // Down & Second (S)

  // define the brightness
  int bright_value = analogRead(A0);
  Serial.println(bright_value);

  // define the Joystick for alarm
  // var for joystcik controlled alarm
  pinMode(VRx, INPUT);  // X : > 400 Left; 0 - 50 stay; < -400 right
  pinMode(VRy, INPUT);  // Y : < -400 UP; 0 - 50 stay; > 400 down
  pinMode(SW, INPUT_PULLUP); // SW: 0 push;

  // define the buzzer
  pinMode(buzzer, OUTPUT);



  // Initialize the Serial for time display
  Serial.begin(9600);
  Serial.print("compiled: ");
  Serial.print(__DATE__);
  Serial.println(__TIME__);

  // Initialize RTC object
  Rtc.Begin();

  // Define the RTC initial time
  RtcDateTime compiled = RtcDateTime(__DATE__, __TIME__);
  printTime(compiled);

  // Set time to system time and print it
  Rtc.SetDateTime(compiled);
  Serial.println();

  // Error check for RTC
  // Time invalid case
  if (!Rtc.IsDateTimeValid())
  {
    if (Rtc.LastError() != 0)
    {
      Serial.print("RTC communications error = ");
      Serial.println(Rtc.LastError());
    }
    else
    {
      Serial.println("RTC lost confidence in the DateTime!");
      Rtc.SetDateTime(compiled);
    }
    // Red LED alert
    for (int i = 0; i < 3; ++i)
    {
      digitalWrite(13, HIGH);
      delay(500);
      digitalWrite(13, LOW);
    }
  }

  // RTC isn't running case
  if (!Rtc.GetIsRunning())
  {
    Serial.println("RTC was not actively running, starting now");
    Rtc.SetIsRunning(true);
    // Red LED alert
    for (int i = 0; i < 3; ++i)
    {
      digitalWrite(13, HIGH);
      delay(500);
      digitalWrite(13, LOW);
    }
  }


  // Initialize current time
  RtcDateTime now = Rtc.GetDateTime();
  if (now < compiled) // make sure the compile time is older than RTC
  {
    Serial.println("RTC is older than compile time!  (Updating DateTime)");
    Rtc.SetDateTime(compiled);
  }

  // Set up the RTC Pin
  // never assume the Rtc was last configured by you, so
  // just clear them to your needed state
  Rtc.SetSquareWavePin(DS1307SquareWaveOut_Low);

  // Time memory
  /* comment out on a second run to see that the info is stored long term */
  // Store something in memory on the RTC
  Rtc.SetMemory(0, 13);
  uint8_t written = Rtc.SetMemory(13, (const uint8_t*)data, sizeof(data) - 1); // remove the null terminator strings add
  Rtc.SetMemory(1, written);
  /* end of comment out section */


  // Intialize the object
  myDisplay.begin();

  // Set the intensity (brightness) of the display (0-15)
  if (bright_value > 700) {
    myDisplay.setIntensity(0); // brighter in day
  }
  else {
    myDisplay.setIntensity(10); // darker in night
  }

  // Clear the display
  myDisplay.displayClear();

}

void loop() {

  // RTC error check
  if (!Rtc.IsDateTimeValid())
  {
    if (Rtc.LastError() != 0)
    {
      Serial.print("RTC communications error = ");
      Serial.println(Rtc.LastError());
    }
    else
    {
      // Common Causes:
      //    1) the battery on the device is low or even missing and the power line was disconnected
      Serial.println("RTC lost confidence in the DateTime!");
    }
    // Red LED alert
    for (int i = 0; i < 3; ++i)
    {
      digitalWrite(13, HIGH);
      delay(500);
      digitalWrite(13, LOW);
    }
  }

  // Set up current time
  RtcDateTime now = Rtc.GetDateTime();
  //Print time for check
  printTime(now);
  Serial.println();

  // ________
  //delay(5000);

  // get the offset we stored our data from address zero
  uint8_t address = Rtc.GetMemory(0);
  // Address check
  if (address != 13)
  {
    Serial.println("address didn't match");
  }
  else
  {
    // get the size of the data from address 1
    uint8_t count = Rtc.GetMemory(1);
    uint8_t buff[20];

    // get our data from the address with the given size
    uint8_t gotten = Rtc.GetMemory(address, buff, count);

    // remove the extra null terminator strings add
    if (gotten != count || count != sizeof(data) - 1)
    {
      Serial.print("something didn't match, count = ");
      Serial.print(count, DEC);
      Serial.print(", gotten = ");
      Serial.print(gotten, DEC);
      Serial.println();
      // Red LED alert
      for (int i = 0; i < 3; ++i)
      {
        digitalWrite(13, HIGH);
        delay(500);
        digitalWrite(13, LOW);
      }
    }
    Serial.print("data read (");
    Serial.print(gotten);
    Serial.print(") = \"");
    for (uint8_t ch = 0; ch < gotten; ch++)
    {
      Serial.print((char)buff[ch]);
    }
    Serial.println("\"");
  }
  //delay(5000);


  dateButtonState = digitalRead(Up);
  secondButtonState = digitalRead(Down);
  printDayTime(now, myDisplay);
  if (dateButtonState == LOW) {
    printDateTime(now, myDisplay);
  }
  else if (secondButtonState == LOW) {
    printSeconds(now, myDisplay);
  }

  // Setting alarm
  SW_state = digitalRead(SW);
  mapX = map(xPosition, 0, 1023, -512, 512);
  mapY = map(yPosition, 0, 1023, -512, 512);
  int alarm_H = 0;
  int alarm_M = 0;
  bool isAlarm = false;
  if (SW_state == 0) { // SW been pressed, begin setting
    isAlarm = true;
  }

  int theAlarm[] = {0, 0}; // save the alarm time
  int pointer = 0; // save current place of alarm array
  while (isAlarm) { // begin setting
    digitalWrite(13, HIGH); // light up
    xPosition = analogRead(VRx); // left or right
    yPosition = analogRead(VRy); // up or down
    myDisplay.setTextAlignment(PA_LEFT);
    myDisplay.print(theAlarm[0] + "." + theAlarm[1]);
    if (xPosition > 400 or xPosition < -400) { // change x direction, hour or mintues
      if (pointer == 0 ) {
        pointer = 1;
      }
      else {
        pointer = 0;
      }
    }
    if (yPosition < -400) { // go up
      if (pointer == 0 ) { //  hour seeting
        if (theAlarm[pointer] < 23 and theAlarm[pointer] > -1) // between 0 and 23
        {
          theAlarm[pointer] ++;
        }
        else
        {
          theAlarm[pointer] = 0;
        }
      }
      else { //  minutes setting
        if (theAlarm[pointer] < 59 and theAlarm[pointer] > -1) // between 0 and 59
        {
          theAlarm[pointer] ++;
        }
        else
        {
          theAlarm[pointer] = 0;
        }
      }

    }
    if (yPosition > 400) { // go down
      if (pointer == 0 ) { //  hour seeting
        if (theAlarm[pointer] < 24 and theAlarm[pointer] > 0) // between 1 and 24
        {
          theAlarm[pointer] --;
        }
        else
        {
          theAlarm[pointer] = 0;
        }
      }
      else { // minutes setting
        if (theAlarm[pointer] < 60 and theAlarm[pointer] > 1) // between 1 and 60
        {
          theAlarm[pointer] --;
        }
        else
        {
          theAlarm[pointer] = 0;
        }
      }
    }
    if (SW_state == 0) { // SW been pressed, end setting
      isAlarm = false;
    }
    digitalWrite(13, LOW);
    pointer = 0;
    delay(500);
  }


  // Alarm check
  if (now.Hour() == theAlarm[0] and now.Minute() == theAlarm[1]) {
    tone(buzzer, 1000); // Send 1KHz sound signal
    delay(4000);        // sound for 4 sec
    noTone(buzzer);     // Stop sound...
    delay(500);
  }

  // loop ending
  delay(1000);
}

// General time display through Serial
void printTime(const RtcDateTime& dt)
{
  char timestring[20];
  snprintf_P(timestring,
             countof(timestring),
             PSTR("%02u/%02u/%04u"),
             dt.Month(),
             dt.Day(),
             dt.Year(),
             dt.Hour(),
             dt.Minute(),
             dt.Second() );
  Serial.print(timestring);
}

// Display date time, like Month, Day
void printDateTime(const RtcDateTime& dt, const MD_Parola& myDisplay)
{
  char datestring[20];
  snprintf_P(datestring,
             countof(datestring),
             PSTR("%02u/%02u"),
             dt.Month(),
             dt.Day() );
  Serial.print(datestring);
  myDisplay.displayClear();
  myDisplay.setTextAlignment(PA_CENTER);
  myDisplay.print(datestring);
}

// Display hours,minutes
void printDayTime(const RtcDateTime& dt, const MD_Parola& myDisplay)
{
  char daystring[20];
  snprintf_P(daystring,
             countof(daystring),
             PSTR("%02u:%02u"),
             dt.Hour(),
             dt.Minute());
  Serial.print(daystring);
  myDisplay.displayClear();
  myDisplay.setTextAlignment(PA_CENTER);
  myDisplay.print(daystring);
}

// Display seconds
void printSeconds(const RtcDateTime& dt, const MD_Parola& myDisplay)
{
  char Seconds[20];
  snprintf_P(Seconds,
             countof(Seconds),
             PSTR("Sec:%02u"),
             dt.Second());
  Serial.print(Seconds);
  myDisplay.displayClear();
  myDisplay.setTextAlignment(PA_LEFT);
  myDisplay.print(Seconds);
}

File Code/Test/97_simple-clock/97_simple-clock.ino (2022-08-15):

#include <LedControl.h>
#include <Wire.h>
#include <RtcDS1307.h>
#include <Servo.h>
#include <EEPROM.h>

// example RTC code modified from :
// https://github.com/Makuna/Rtc/blob/master/examples/DS1307_Simple/DS1307_Simple.ino

// LED Display Code from:
// https://playground.arduino.cc/Main/LedControl/

// Pin 13 has an LED connected on most Arduino boards, including this clock
#define PIN_BLINKY_LED    13

// System constants
#define LOOP_PERIOD       10
#define COLON_BLINK_TIME (100 / LOOP_PERIOD)

// LED Controller pins
#define PIN_LED_CONTROLLER_DATA   10
#define PIN_LED_CONTROLLER_CLK    9
#define PIN_LED_CONTROLLER_LOAD   8

#define LED_BRIGHTNESS_MIN        0
#define LED_BRIGHTNESS_MAX        16
#define LED_BRIGHTNESS_DEFAULT    6

// Light sensor photo resistor
#define PIN_LIGHT_SENSOR            A0

#define LIGHT_SENSOR_AMBIENT        950
#define LIGHT_SENSOR_GAIN           100

#define LIGHT_SENSOR_LPF            100.0


// Light sensor
float light_sensor_lpf = LIGHT_SENSOR_AMBIENT;

void light_sensor_update() {
  int light_sensor_val = analogRead(PIN_LIGHT_SENSOR);
  light_sensor_lpf = ((float)light_sensor_val + (light_sensor_lpf * (LIGHT_SENSOR_LPF - 1.0))) / LIGHT_SENSOR_LPF;
}

int brightness_adjust() {
  // compute the light sensor brightness adjustment
  float brightness_adjust;
  brightness_adjust = (light_sensor_lpf - (float)(LIGHT_SENSOR_AMBIENT)) / (float)(LIGHT_SENSOR_GAIN) ;
  return (int)brightness_adjust;
}


// Create a new LedControl object.
// We use pins 8, 9 and 10 on the Arduino for the SPI interface
// Pin 10 is connected to the DATA IN-pin of the first MAX72XX
// Pin 9 is connected to the CLK-pin of the first MAX72XX
// Pin 8 is connected to the LOAD(/CS)-pin of the first MAX72XX
// There will only be a single MAX72XX attached to the arduino
LedControl display = LedControl(PIN_LED_CONTROLLER_DATA, PIN_LED_CONTROLLER_CLK,
                                PIN_LED_CONTROLLER_LOAD, 1);

// RTC setup.  We use a DS1307 RTC
RtcDS1307<TwoWire> Rtc(Wire);

// Maps the day IDs 0-6 to human readable day strings starting with Sunday == 0.
const char *DayOfWeekString(int DoW) {
  switch (DoW) {
  case 0:
    return "Sun";
  case 1:
    return "Mon";
  case 2:
    return "Tue";
  case 3:
    return "Wed";
  case 4:
    return "Thu";
  case 5:
    return "Fri";
  case 6:
    return "Sat";
  default:
    return "---";
  }
}

// Formats and writes the given time to the LED display.
void DisplayTime(const RtcDateTime *time) {
  // read the current time
  uint8_t hour = time->Hour();
  uint8_t minute = time->Minute();

  // handle 12-hour time silliness
  if (hour == 0) {
    hour = 12;
  }
  if (hour > 12) {
    hour = hour - 12;
  }
  // Hide the hour 10s place if the hour is less than 10
  if (hour >= 10) {
    display.setDigit(0, 0, 1, false);
  } else {
    display.setChar(0, 0, ' ', false);
  }
  display.setDigit(0, 1, hour % 10, false);
  display.setDigit(0, 2, minute / 10, false);
  display.setDigit(0, 3, minute % 10, false);
}


// Formats and prints the given time to the UART.
void PrintTime(const RtcDateTime *time) {
  uint8_t hour = time->Hour();
  // handle 12-hour time silliness
  boolean pm = false;
  if (hour == 0) {
    hour = 12;
  } else if (hour > 12) {
    hour -= 12;
    pm = true;
  }
  uint8_t minute = time->Minute();
  uint8_t second = time->Second();

  // format a descriptive time/date output with DOW and 12-hour format
  Serial.print(DayOfWeekString(time->DayOfWeek()));
  Serial.print(" ");
  Serial.print(time->Year(), DEC);
  Serial.print("-");
  Serial.print(time->Month(), DEC);
  Serial.print("-");
  Serial.print(time->Day(), DEC);
  Serial.print(" ");
  Serial.print(hour, DEC);
  Serial.print(":");
  if (minute < 10) {
    Serial.print("0");
  }
  Serial.print(minute, DEC);
  Serial.print(":");
  if (second < 10) {
    Serial.print("0");
  }
  Serial.print(second, DEC);
  if (pm) {
    Serial.print(" pm");
  } else {
    Serial.print(" am");
  }
  Serial.print("  light:");
  //Serial.print(analogRead(PIN_LIGHT_SENSOR), DEC);
  //Serial.print(",");
  Serial.print(light_sensor_lpf, 1);
  Serial.print(",");
  Serial.print(brightness_adjust());

  Serial.println("");
}


// The Arduino setup routine runs once when you press reset:
void setup() {
  // initialize the digital pin as an output.
  pinMode(PIN_BLINKY_LED, OUTPUT);

  // setup setial port
  Serial.begin(115200);

  // Start the I2C interface
  Wire.begin();
  Rtc.Begin();

  // Setup and check the time on the RTC clock
  RtcDateTime time_compiled = RtcDateTime(__DATE__, __TIME__);
  if (!Rtc.IsDateTimeValid()) {
    if (Rtc.LastError() != 0) {
      // we have a communications error
      // see https://www.arduino.cc/en/Reference/WireEndTransmission for
      // what the number means
      Serial.print("RTC communications error = ");
      Serial.println(Rtc.LastError());
    } else {
      // Common Causes:
      //    1) first time you ran and the device wasn't running yet
      //    2) the battery on the device is low or even missing

      Serial.println("RTC lost confidence in the DateTime!");
      // following line sets the RTC to the date & time this sketch was compiled
      // it will also reset the valid flag internally unless the Rtc device is
      // having an issue

      Rtc.SetDateTime(time_compiled);
    }
  }

  if (!Rtc.GetIsRunning()) {
    Serial.println("RTC was not actively running, starting now");
    Rtc.SetIsRunning(true);
  }

  Serial.print("Compile time=");
  Serial.print(uint32_t(time_compiled), DEC);
  Serial.print(" :");
  PrintTime(&time_compiled);

  RtcDateTime time_now = Rtc.GetDateTime();
  Serial.print("    RTC time=");
  Serial.print(uint32_t(time_now), DEC);
  Serial.print(" :");
  PrintTime(&time_now);

  // figure out if we should keep the RTC time or take the compiled time
  if (uint32_t(time_now) < uint32_t(time_compiled)) {
    Serial.println("RTC is older than compile time!  (Updating DateTime)");
    Rtc.SetDateTime(time_compiled);
  } else if (uint32_t(time_now) > uint32_t(time_compiled)) {
    Serial.println("RTC is newer than compile time. (this is expected)");
  } else if (uint32_t(time_now) == uint32_t(time_compiled)) {
    Serial.println(
        "RTC is the same as compile time! (not expected but all is fine)");
  }
  // uncomment this line to force the RTC to take the compiled time
  //Rtc.SetDateTime(time_compiled);

  // disable the square wave output
  Rtc.SetSquareWavePin(DS1307SquareWaveOut_Low);

  // wake up the MAX72XX from power-saving mode
  display.shutdown(0, false);
  display.setIntensity(0, LED_BRIGHTNESS_DEFAULT);

}


// State used in the loop, which must be global because of the way arduino
// exposes the loop() function. Rather than declaring this on the stack in main
// we make it global so the values persist between loop iterations.
uint8_t second_old = 0;
uint16_t colon_blink_counter = 0;
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

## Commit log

2022-06-03 My first design comment
    [Yuwei_Clock1.0.kicad_pcb, Yuwei_Clock1.0.kicad_sch]
2022-06-12 LED blink
2022-06-12 New schematic of week 1
    [Yuwei_Clock1.0.kicad_sch]
2022-06-12 Change polar capacitor to C_0805_10uf
    [Yuwei_Clock1.0.kicad_pcb, Yuwei_Clock1.0.kicad_sch]
2022-06-15 Update with Arduino Button function
    When button pressed, serial will display string.
2022-06-17 Update with Schematic and PCB
    [Yuwei_Clock1.0.kicad_pcb, Yuwei_Clock1.0.kicad_sch]
2022-06-25 Update with RTC
    [Yuwei_Clock1.0.kicad_pcb, Yuwei_Clock1.0.kicad_sch]
2022-06-29 dot matrix version
    [YWS_clock.kicad_pcb, YWS_clock.kicad_sch]
2022-07-01 Update Buzzer and joystick
    [YWS_clock.kicad_sch]
2022-07-01 update PCB and Schematic with dot matrix
    [YWS_clock.kicad_pcb]
2022-07-01 Update button
    [YWS_clock.kicad_sch]
2022-07-02 Update with PCB layout
    [YWS_clock.kicad_pcb, YWS_clock.kicad_sch]
2022-07-02 update with supplementary material and dot matrix display code
    [YWS_clock.csv, YWS_clock.kicad_sch]
2022-07-07 Add ICSP and separate sections
    [YWS_clock.kicad_pcb, YWS_clock.kicad_sch]
2022-07-17 Initial version with full routing and test point
    [YWS_clock.csv, YWS_clock.kicad_pcb, YWS_clock.kicad_sch]
2022-07-17 Update with gerbers and BOM
    [YWS_clock-B_Cu.gbr, YWS_clock-B_Mask.gbr, YWS_clock-B_Paste.gbr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]
2022-07-17 Update with STEP file
    [YWS_clock.step]
2022-07-22 live review update
    [YWS_clock-B_Cu.gbr, YWS_clock-B_Mask.gbr, YWS_clock-B_Paste.gbr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]
2022-07-22 update with modified PCB
    [YWS_clock.kicad_pcb, YWS_clock.kicad_sch]
2022-07-22 Final version for final review
    [YWS_clock-B_Cu.gbr, YWS_clock-B_Mask.gbr, YWS_clock-B_Paste.gbr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]
2022-07-22 3 error fixed
    [YWS_clock.kicad_pcb, YWS_clock.kicad_sch]
2022-07-22 update with gerber, BOM, drill
    [YWS_clock-B_Cu.gbr, YWS_clock-B_Mask.gbr, YWS_clock-B_Paste.gbr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]
2022-07-22 flip the power init
    [YWS_clock-B_Cu.gbr, YWS_clock-B_Mask.gbr, YWS_clock-B_Paste.gbr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]
2022-08-14 Update with Code and file separations
    [APHB1608.step, Crystal_SMD_4P_2520.step, HPS_Rectangular_Clock.kicad_pcb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]
2022-08-15 Update with test code and delete HPS lib
    [APHB1608.step, Crystal_SMD_4P_2520.step, HPS_Rectangular_Clock.kicad_pcb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]
